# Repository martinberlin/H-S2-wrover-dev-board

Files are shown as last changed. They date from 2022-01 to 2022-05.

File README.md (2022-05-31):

## An open source S2-WROVER board with minimun components and DFU USB

H stands for Hardware. **IMPORTANT NOTE: Please do not intend to build this PCB. **
It was my first EPDiy like controller and has a lot of newbie defects. Including selecting no REAL TIME pins from the IO MUX to use as Clock and Start pulse for I2S. As is won't work, and in the next months, I won't have time to play with electronics.

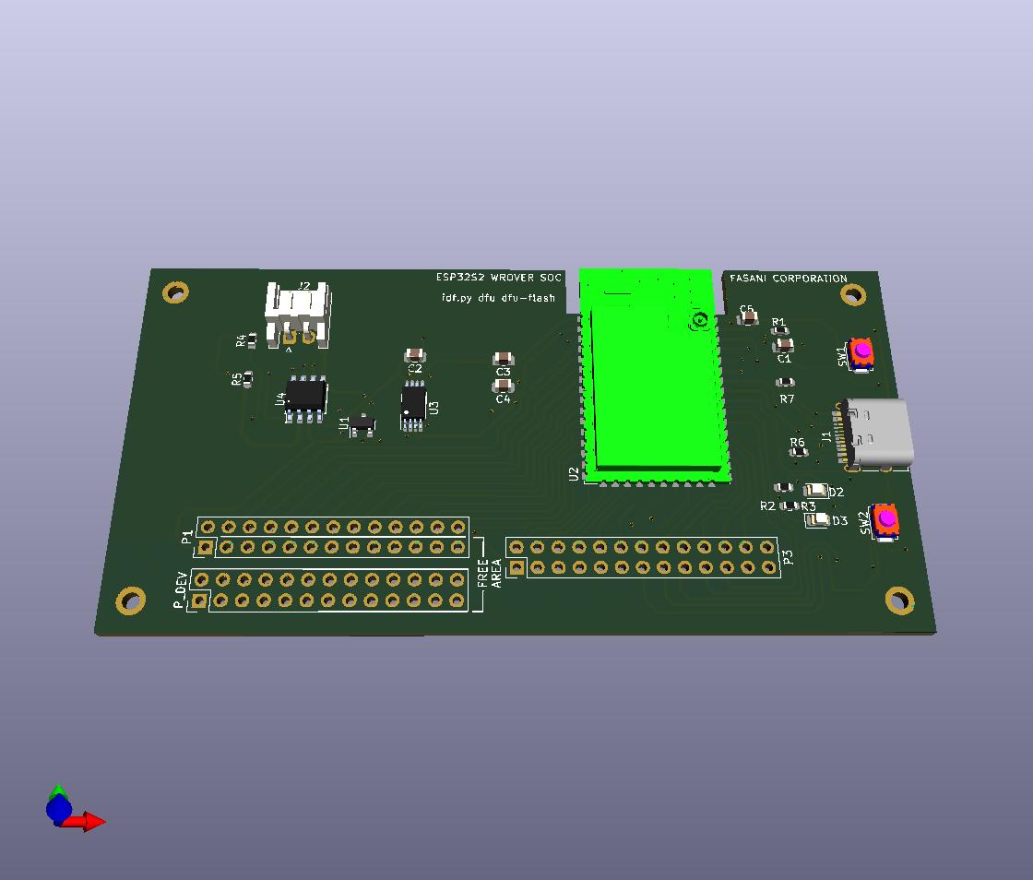
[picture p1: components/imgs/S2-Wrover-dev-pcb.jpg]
PCB preview

Initial dimensions:
99x50mm
PCB preview-back
PCB layers
Note: Previews are taken from the [v1 branch](https://github.com/martinberlin/H-S2-wrover-dev-board/tree/v1).

This board aims to be the simplest possible configuration to have a breakout PCB to start developing something with Espressif S2.
The minimun requirements are:

- Lipo charger and a 2 leds indicator (charge, full)
- All GPIOs exposed
- No Serial-to-UART. Only dfu USB, please check this [blog post from Espressif](https://blog.espressif.com/dfu-using-the-native-usb-on-esp32-s2-for-flashing-the-firmware-b2c4af3335f1)
- Only 2 layer (Cheaper to fabricate)
- **Important** For simplicity this test board has no Auto-Reset circuit (Check [epdiy Schematic](https://github.com/martinberlin/H-S2-wrover-dev-board/tree/epd-v1/Schematic))

## EPDiy S2 PCB

In the **epd-v1** branch it's my first attempt to design an EPDiy V6 clone. This is still on fabrication and as the prototype Revision 1.1 still need a lot of tests and adjustments.
This will be probably merged in master once is tested and working as expected. Being my first somehow complex ESP32S2 boards I will for sure 

Both boards Still a work in progress, no Gerbers, no pick-place and no production files at all. It needs testing before everything can be published.

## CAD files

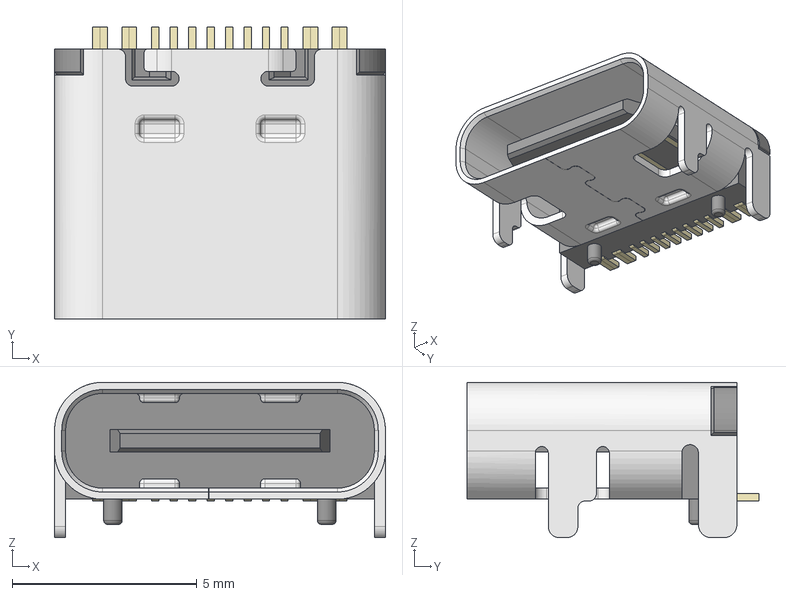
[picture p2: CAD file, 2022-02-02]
components/3dmodels/HRO_TYPE-C-31-M-12.step
8.95 x 7.90 x 4.20 mm

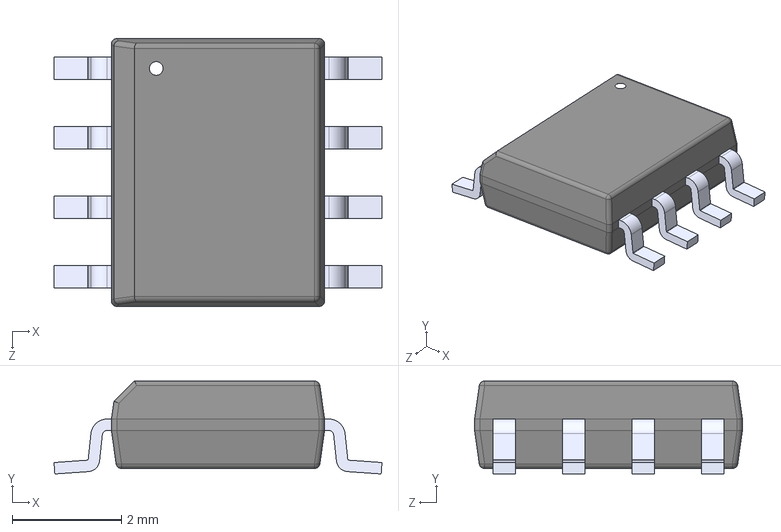
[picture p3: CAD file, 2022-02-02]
components/3dmodels/TP4056.step
6.00 x 1.70 x 4.90 mm

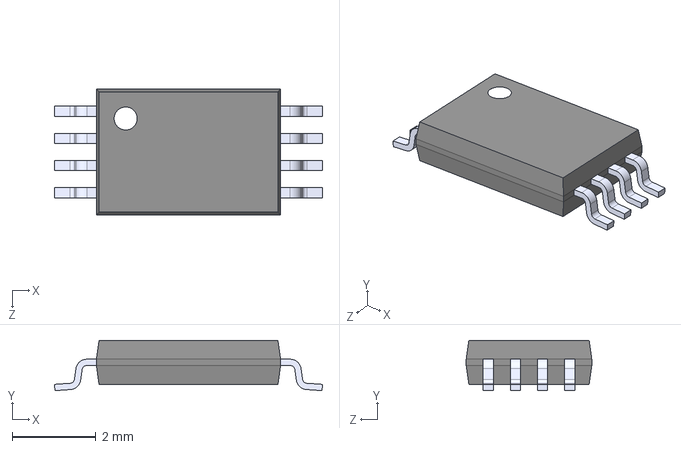
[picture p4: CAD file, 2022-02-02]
components/3dmodels/tps2113apwr.step
6.40 x 1.20 x 3.00 mm

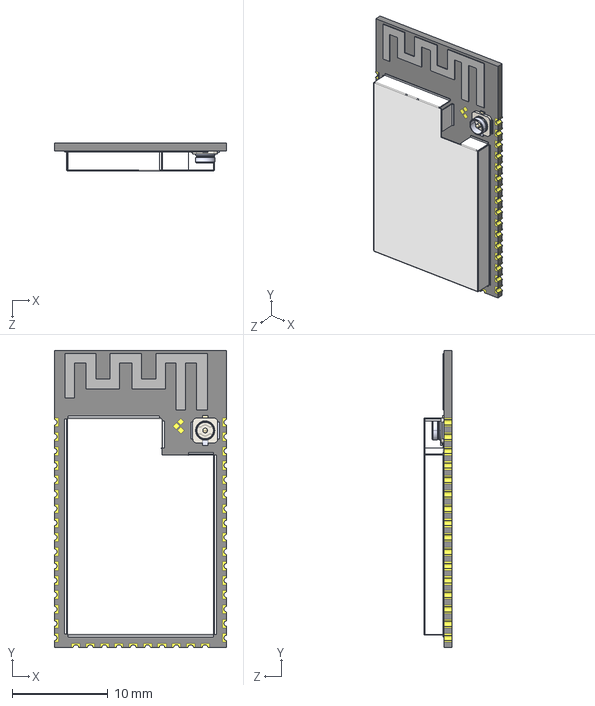
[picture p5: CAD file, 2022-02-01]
components/3dmodels/ESP32-S2-WROVER.STEP
18.0 x 31.0 x 2.91 mm

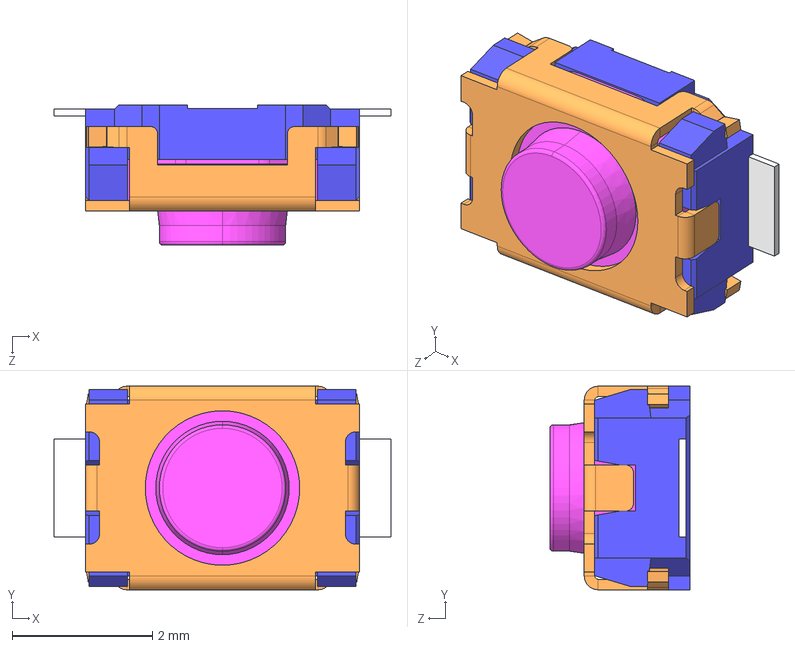
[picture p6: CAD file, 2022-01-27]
components/3dmodels/SKRKAH.STEP
4.80 x 2.90 x 2.00 mm

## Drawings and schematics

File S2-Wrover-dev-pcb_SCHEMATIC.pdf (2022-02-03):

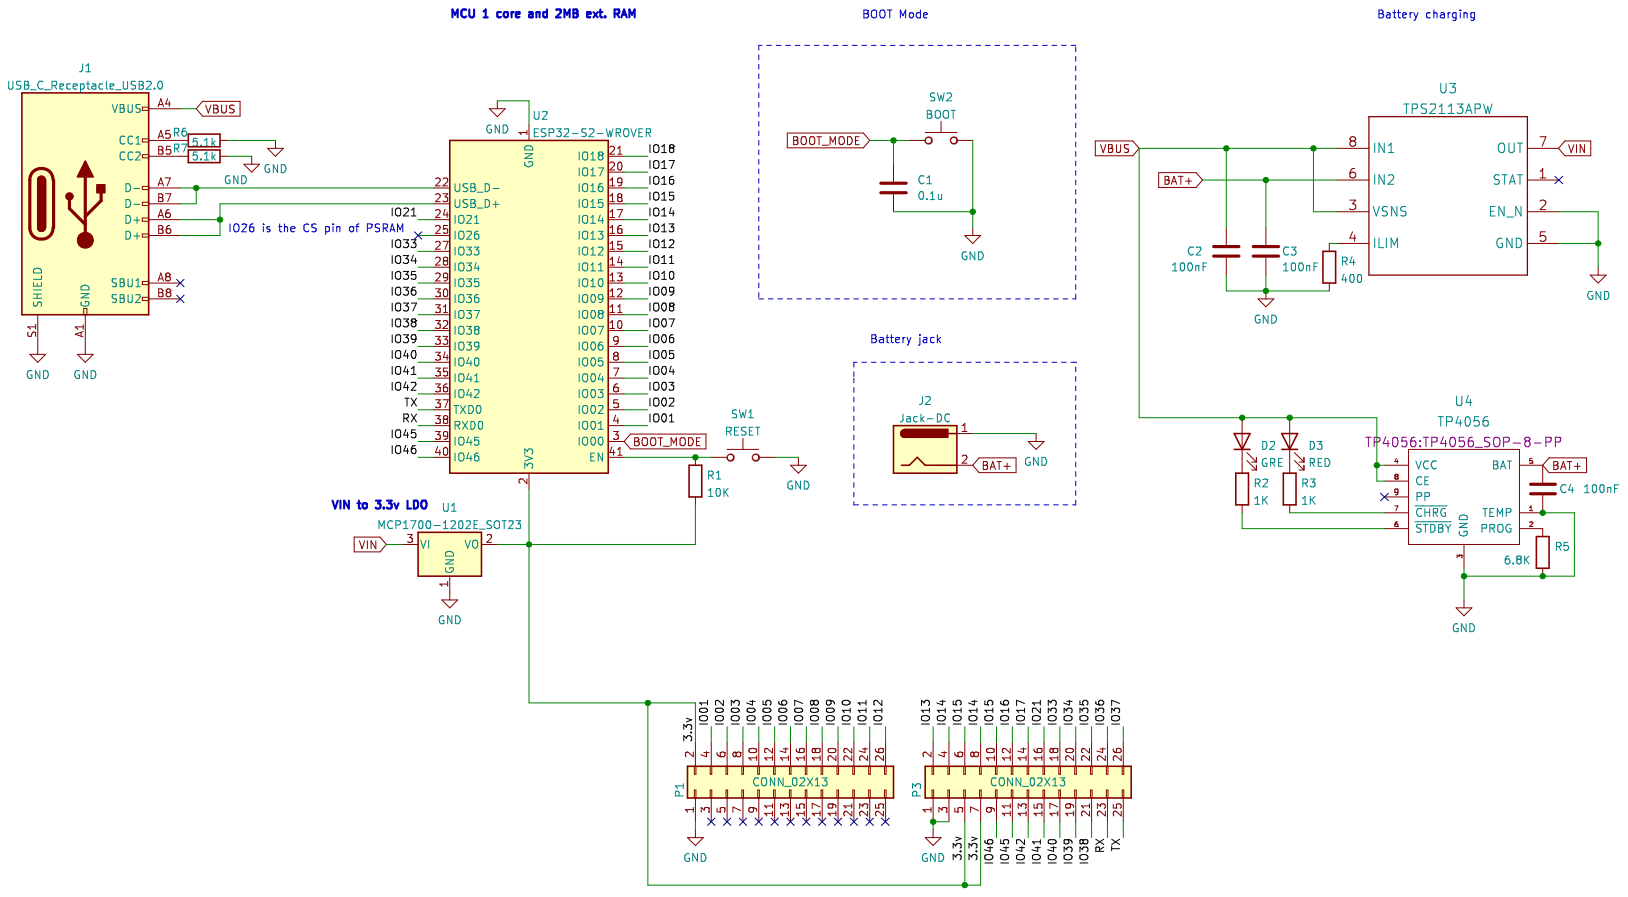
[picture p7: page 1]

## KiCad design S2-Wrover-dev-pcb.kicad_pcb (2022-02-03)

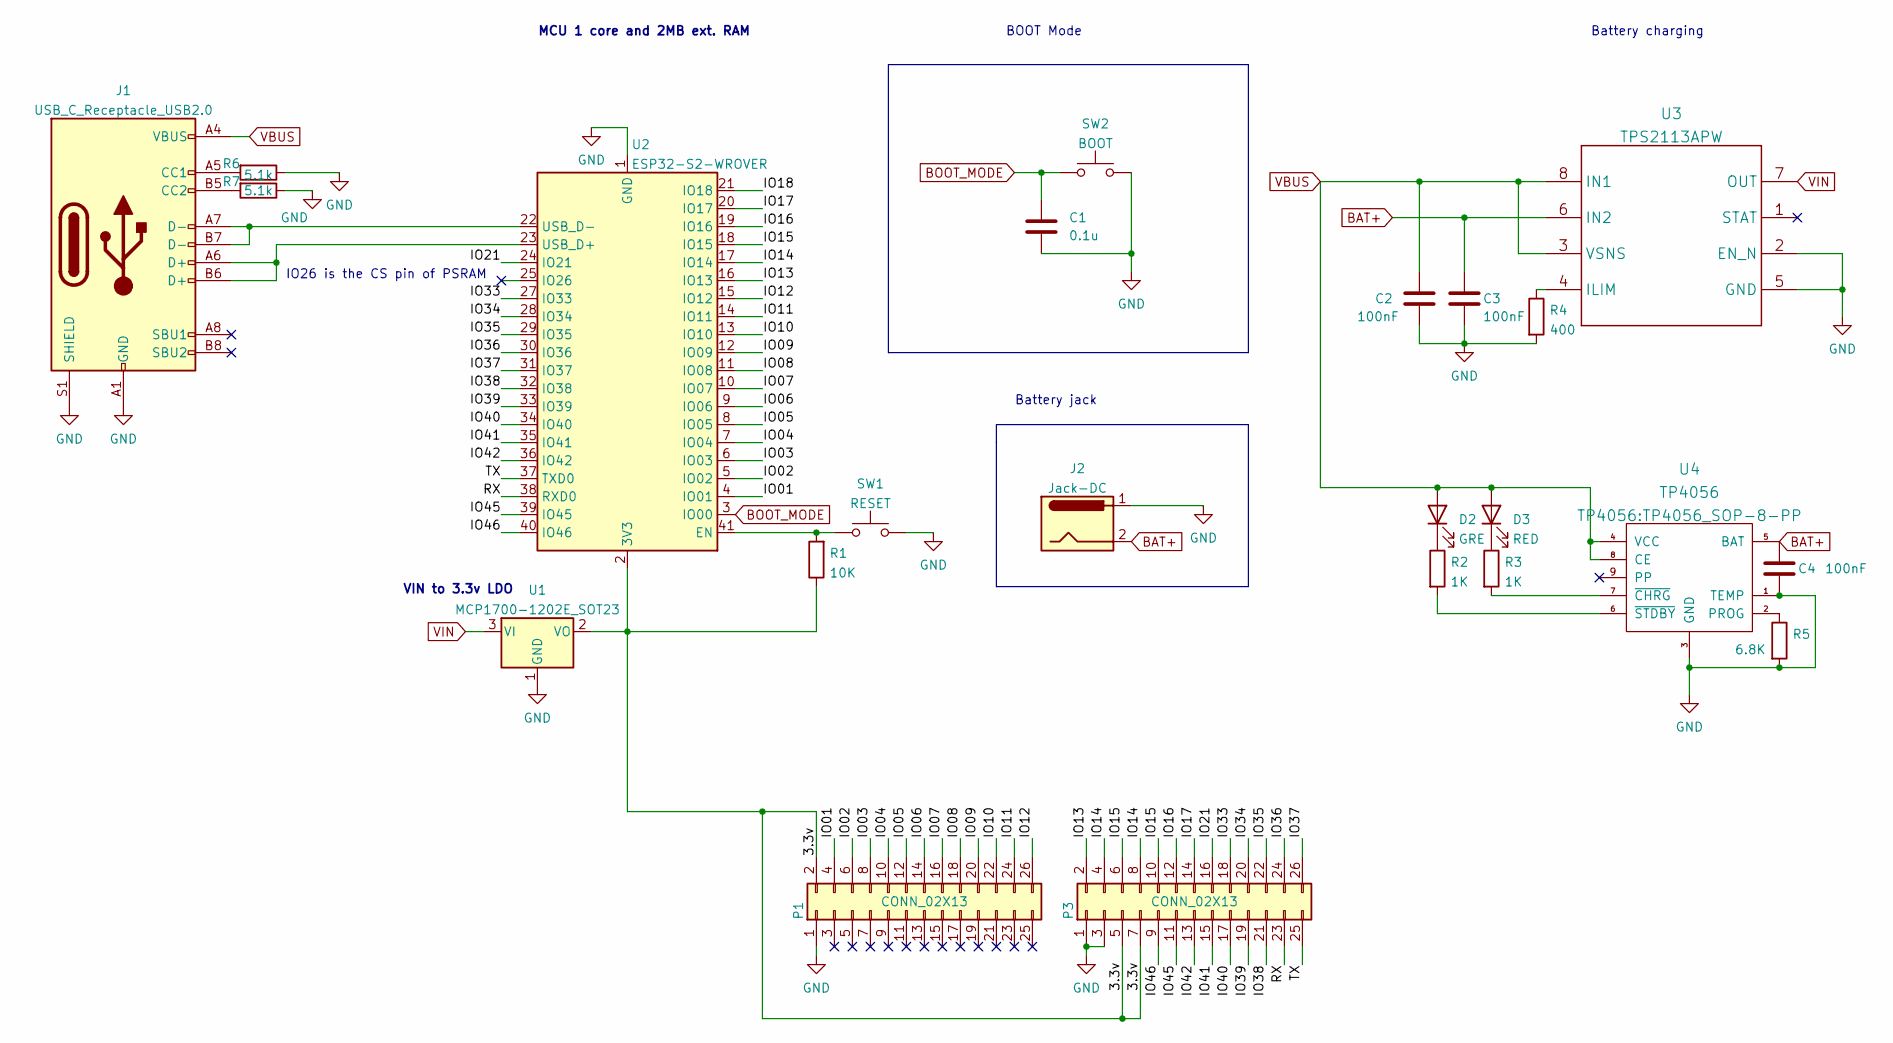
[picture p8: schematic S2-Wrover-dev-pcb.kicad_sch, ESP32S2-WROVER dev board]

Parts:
C1: 0.1u; C_0805_2012Metric
C2, C3, C4: 100nF; C_0805_2012Metric
D2: GRE; LED_0805_2012Metric
D3: RED; LED_0805_2012Metric
J1: USB_C_Receptacle_USB2.0; USB_C_Receptacle_HRO_TYPE-C-31-M-12; LCSC C165948
J2: Jack-DC; JST_EH_S2B-EH_1x02_P2.50mm_Horizontal
P1, P3: CONN_02X13; PinHeader_2x13_P2.54mm_Vertical
R1: 10K; R_0603_1608Metric
R2, R3: 1K; R_0603_1608Metric
R4: 400; R_0603_1608Metric
R5: 6.8K; R_0603_1608Metric
R6, R7: 5.1k; R_0603_1608Metric
SW1: RESET; Alps_SKRK
SW2: BOOT; Alps_SKRK
U1: MCP1700-1202E_SOT23; SOT-23
U2: ESP32-S2-WROVER
U3: TPS2113APW
U4: TP4056; TP4056_SOP-8-PP

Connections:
/3.3v: P1.2, P3.5, P3.7, R1.1, U1.2 (VO), U2.2 (3V3)
/IO01: P1.4, U2.4 (IO01)
/IO02: P1.6, U2.5 (IO02)
/IO03: P1.8, U2.6 (IO03)
/IO04: P1.10, U2.7 (IO04)
/IO05: P1.12, U2.8 (IO05)
/IO06: P1.14, U2.9 (IO06)
/IO07: P1.16, U2.10 (IO07)
/IO08: P1.18, U2.11 (IO08)
/IO09: P1.20, U2.12 (IO09)
/IO10: P1.22, U2.13 (IO10)
/IO11: P1.24, U2.14 (IO11)
/IO12: P1.26, U2.15 (IO12)
/IO13: P3.2, U2.16 (IO13)
/IO14: P3.4, P3.8, U2.17 (IO14)
/IO15: P3.6, P3.10, U2.18 (IO15)
/IO16: P3.12, U2.19 (IO16)
/IO17: P3.14, U2.20 (IO17)
/IO18: U2.21 (IO18)
/IO21: P3.16, U2.24 (IO21)
/IO33: P3.18, U2.27 (IO33)
/IO34: P3.20, U2.28 (IO34)
/IO35: P3.22, U2.29 (IO35)
/IO36: P3.24, U2.30 (IO36)
/IO37: P3.26, U2.31 (IO37)
/IO38: P3.21, U2.32 (IO38)
/IO39: P3.19, U2.33 (IO39)
/IO40: P3.17, U2.34 (IO40)
/IO41: P3.15, U2.35 (IO41)
/IO42: P3.13, U2.36 (IO42)
/IO45: P3.11, U2.39 (IO45)
/IO46: P3.9, U2.40 (IO46)
/RX: P3.23, U2.38 (RXD0)
/TX: P3.25, U2.37 (TXD0)
BAT+: C3.2, C4.2, J2.2, U3.6 (IN2), U4.5 (BAT)
BOOT_MODE: C1.2, SW2.1, U2.3 (IO00)
GND: C1.1, C2.1, C3.1, C4.1, J1.A1 (GND), J1.A12 (GND), J1.B1 (GND), J1.B12 (GND), J1.S1 (SHIELD), J2.1, P1.1, P3.1, P3.3, R4.2, R5.2, R6.1, R7.1, SW1.2, SW2.2, U1.1 (GND), U2.1 (GND), U2.26 (GND), U2.42 (GND), U2.43 (GND), U3.2 (EN_N), U3.5 (GND), U4.1 (TEMP), U4.3 (GND)
unnamed: D2.1 (K), R2.1
unnamed: D3.1 (K), R3.1
unnamed: J1.A5 (CC1), R6.2
unnamed: J1.A6 (D+), J1.B6 (D+), U2.23 (USB_D+)
unnamed: J1.A7 (D-), J1.B7 (D-), U2.22 (USB_D-)
unnamed: J1.B5 (CC2), R7.2
unnamed: R1.2, SW1.1, U2.41 (EN)
unnamed: R2.2, U4.6 (~STDBY)
unnamed: R3.2, U4.7 (~CHRG)
unnamed: R4.1, U3.4 (ILIM)
unnamed: R5.1, U4.2 (PROG)
VBUS: C2.2, D2.2 (A), D3.2 (A), J1.A4 (VBUS), J1.A9 (VBUS), J1.B4 (VBUS), J1.B9 (VBUS), U3.3 (VSNS), U3.8 (IN1), U4.4 (VCC), U4.8 (CE)
VIN: U1.3 (VI), U3.7 (OUT)

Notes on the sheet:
Battery charging
Battery jack
BOOT Mode
MCU 1 core and 2MB ext. RAM
IO26 is the CS pin of PSRAM
VIN to 3.3v LDO

Board: 2 copper layers, 28 parts (0 on the bottom side), 49 nets, no tracks yet.

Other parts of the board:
MK1, MK2, MK2#2, MK3: Mounting_Hole; MountingHole_3-5mm
P_DEV: CONN_02X13; PinHeader_2x13_P2.54mm_Vertical

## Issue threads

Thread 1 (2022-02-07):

PMIC tps65185 test project

martinberlin, 2022-02-07:
Pending:

- [ ] Read for once the datasheet till the end ;)
- [ ] Add also a test point for the V3P3 power switch, that needs to be activated by I2C commands
- [ ] Make a test for all I2C commands and check how it reacts

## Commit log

2022-01-27 Add BOOT switch
    [S2-Wrover-dev-pcb.kicad_sch, SKRKAH.STEP]
2022-01-27 ERC needs to pass
    [S2-Wrover-dev-pcb.kicad_sch]
2022-02-01 Update .gitmodules
    Remove esp32-wrover since we use S2-WROVER
2022-02-02 Add schematic
    [S2-Wrover-dev-pcb.kicad_sch]
2022-02-02 Update schematic and assign footprints
    [HRO_TYPE-C-31-M-12.step, S2-Wrover-dev-pcb.kicad_pcb, S2-Wrover-dev-pcb.kicad_sch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]
2022-02-03 Update schematic
    [S2-Wrover-dev-pcb.kicad_pcb, S2-Wrover-dev-pcb.kicad_sch]
